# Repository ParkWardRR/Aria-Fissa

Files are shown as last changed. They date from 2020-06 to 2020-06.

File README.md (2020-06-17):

# Aria Fissa Project
This project hopes to simplify monitoring CO2 levels using Home-Assistant or the more compatible MQTT protocol. 
Aria Fissa uses the easily procurable CO2 sensor (MH-Z19) and the NodeMCU v3.

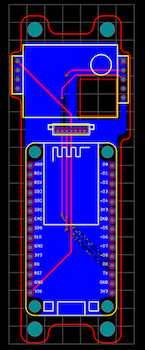
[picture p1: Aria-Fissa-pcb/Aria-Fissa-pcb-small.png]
AriaFissa


## Ingredients

 - MH-Z19 sensor - [Link](https://esphome.io/components/sensor/mhz19.html)
 -  Microcontroller - NodeMCU v3 - [Link](https://docs.zerynth.com/latest/official/board.zerynth.nodemcu3/docs/index.html) 
	- The Aria Fissa PCB might be compatible with other ESP8266  board. Verify the pin count and the RX/TX pin locations 
- Host - You'll need a [MQTT broker](https://en.wikipedia.org/wiki/MQTT#MQTT_broker) or [Home-Assistant](https://www.home-assistant.io/getting-started/) host 
- Computer to configure the board and your host 
- Soldering iron, solder, flux, and other hobbiest tools/consumables

### Optional 
There are few variations of the MH-Z19 - The Aria Fissa board attempts compatablity with most of the available versions. 

There are two options to mount the MH-Z19 to the PCB: 
 -  MH-Z19 by using 2.54mm pitch breakaway male pin headers ( 9 total pins needed) 
 -  There are through-hole solder pads located near the middle of the board for mounting a JST connector. This might provide some users additional mounting options. 
	 - Search for the following: `JST 1.25MM 7 Pin Female Double Connector with Wires 150MM 1007 28 AWG`
	 - *Not all MH-Z19 sensors have a JST mount*

 For mounting the NodeMCU board either solder it directly to the PCB or use `2.54mm Pitch 0.1 1x15 15 Pin 15p Female Dupont Header`
 
 Here is a fully functioning board: 
 
AriaFissa

## Next Steps/Tutorials
Configure the NodeMCU board for your environment

 - MQTT Tutorial
 - [Home-Assistant (using ESPHome)](Aria-Fissa/ESPHome-config/)

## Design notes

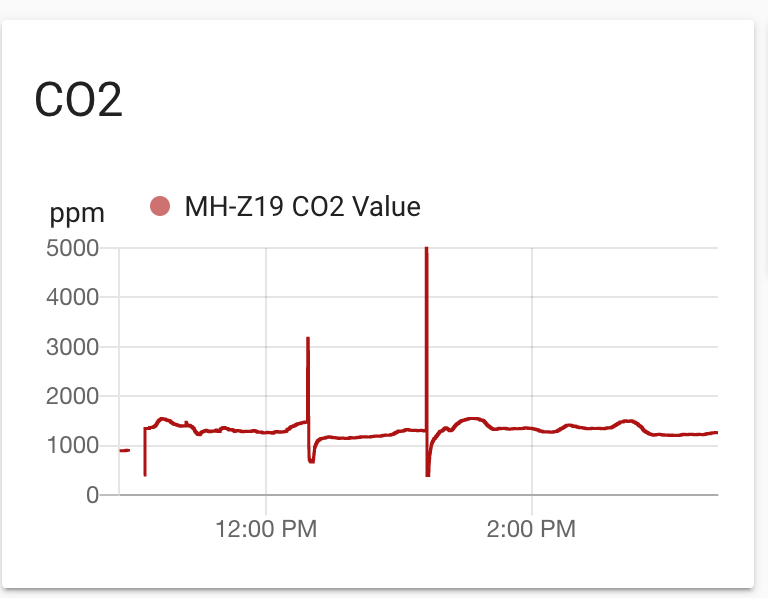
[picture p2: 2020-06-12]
demo/HAS_Panel.png

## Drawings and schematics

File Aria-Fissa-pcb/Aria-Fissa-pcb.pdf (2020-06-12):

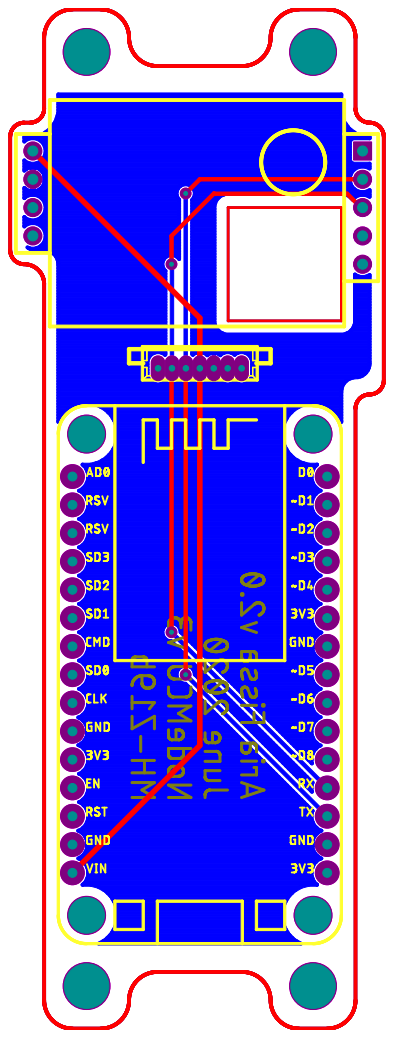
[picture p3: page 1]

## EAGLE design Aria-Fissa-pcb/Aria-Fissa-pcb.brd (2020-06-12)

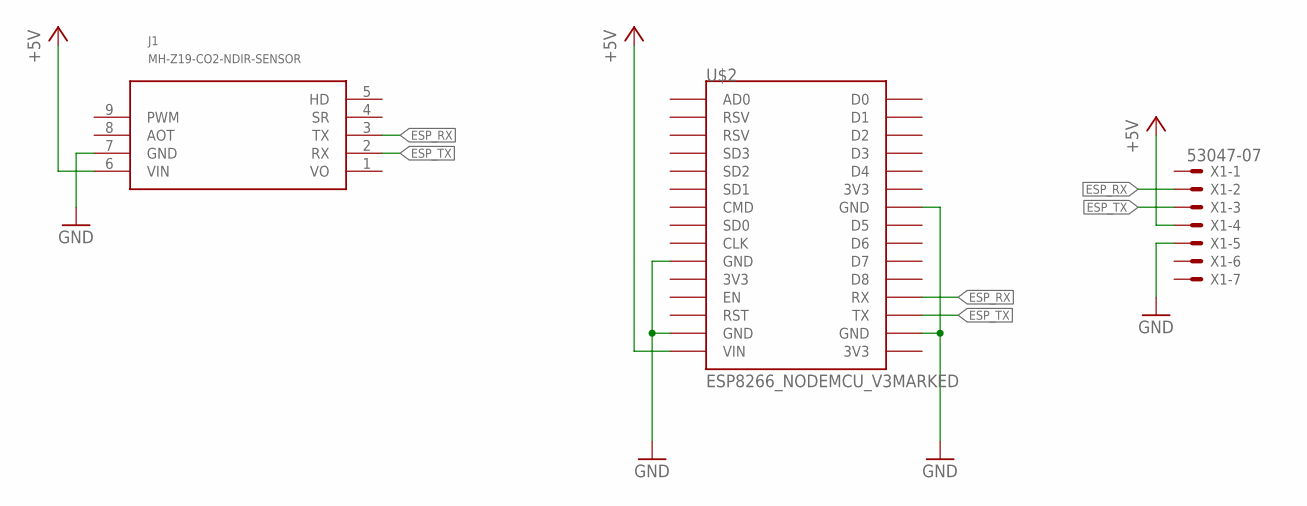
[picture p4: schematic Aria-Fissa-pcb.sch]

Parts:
J1: MH-Z19-CO2-NDIR-SENSOR; MH-Z19
U$2: ESP8266_NODEMCU_V3MARKED; ESP8266_NODEMCU_V3_SMALL
X1: 53047-07

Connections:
+5V: J1.6 (VIN), U$2.VIN, X1.4
ESP_RX: J1.3 (TX), U$2.RX, X1.2
ESP_TX: J1.2 (RX), U$2.TX, X1.3
GND: J1.7 (GND), U$2.GND@0 (GND), U$2.GND@1 (GND), U$2.GND@2 (GND), U$2.GND@3 (GND), X1.5
VO: J1.1 (VO)

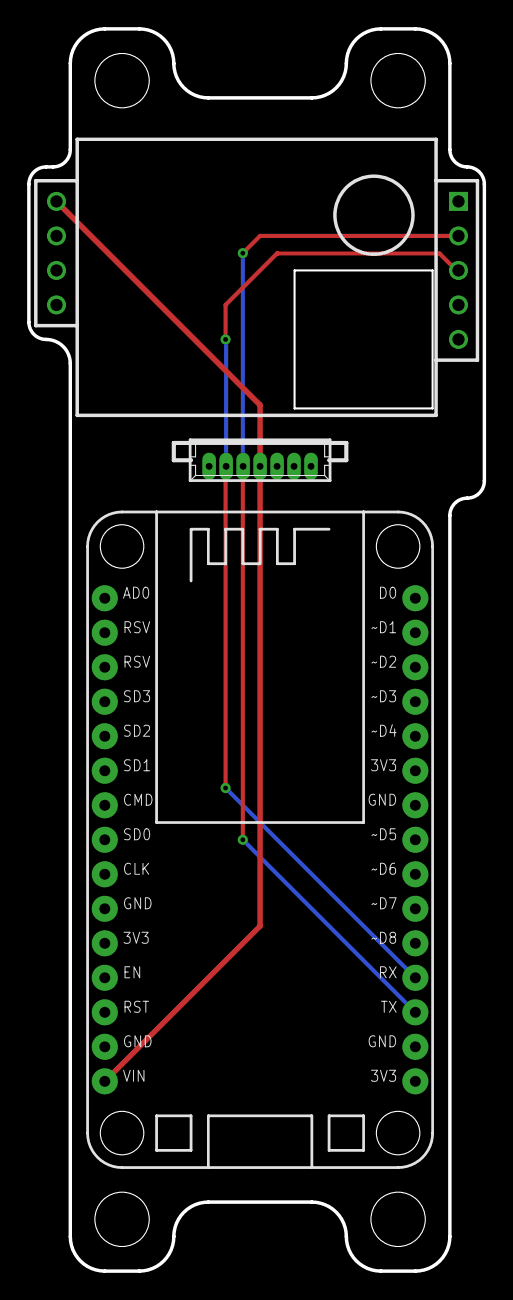
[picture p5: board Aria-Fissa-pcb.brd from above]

Board: 2 copper layers, 33.5 x 91.4 mm, 3 parts (1 on the bottom side), 4 nets.

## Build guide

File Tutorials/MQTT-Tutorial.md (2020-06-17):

This tutorial will walk you through the process of configuring your NodeMCU v3 board for compatablity with a MQTT server

## Ingredients
 - MH-Z19 sensor - [Link](https://esphome.io/components/sensor/mhz19.html)
 -  Microcontroller - NodeMCU v3 - [Link](https://docs.zerynth.com/latest/official/board.zerynth.nodemcu3/docs/index.html) 
	- Be cautious as many sellers are selling other ESP8266 boards in place of the  
	- The Aria Fissa PCB might be compatible with other ESP8266  board. Verify the dimentions, pin count, and the RX/TX pin locations 
- Host - You'll need a [MQTT broker](https://en.wikipedia.org/wiki/MQTT#MQTT_broker)
	- [Eclipse Mosquitto](https://mosquitto.org/) is a popular project  
- Computer to configure the board and your host 
- Soldering iron, solder, flux, and other hobbiest tools/consumables

### Downloads
- [ESPEasy](https://github.com/letscontrolit/ESPEasy/releases) firmware 
	- Look for `espeasy_esp82xx_mega-xxxxxxxxx.zip`

## Warning
The following tutorial will wipe all of the contents of your NodeMCU board.

## Tutorial

 1. Configure and test your serial bootloader utility for your ESP8266
    board  
    - I will be using
    [esptool.py](https://github.com/espressif/esptool) for this tutorial
   2. Connect your ESP8266/NodeMCU to your computer and identify the serial com port
	   - Here is a useful tutorial - [link](mathworks.com/help/supportpkg/arduinoio/ug/find-arduino-port-on-windows-mac-and-linux.html)
	   - For my Mac the nodeMCU v3 is listed as `/dev/tty.SLAB_USBtoUART`
   3. Run the following command to clear the existing bootloader/code/config: 
	   - `esptool.py  --port /dev/tty.SLAB_USBtoUART erase_flash`
	   - Replace `/dev/tty.SLAB_USBtoUART` with the appropriate COM port
   4. Flash the ESPEasy firmware using esptool.py 
	   - The nodemcu v3 board has 4mb of storage and is compatible with most of the ESPEasy packages
	   -  `esptool.py --port /dev/tty.SLAB_USBtoUART write_flash 0x00000 ESP_Easy_mega_20200608_dev_ESP8266_4M1M.bin`
	   -  Once the flash process is complete - disconnect 
   5.
